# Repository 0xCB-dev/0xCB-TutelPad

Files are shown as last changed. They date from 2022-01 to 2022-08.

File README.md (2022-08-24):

# 0xcb-TutelPad
## An 8-key macropad with a 128x64 pixel OLED display

Licence | OSHWA
:-------------------------:|:-------------------------:
 | (https://certification.oshwa.org/nl000009.html)

### Available here:

[KeebSupply](https://keeb.supply/products/0xcb-tutelpad)

### QMK

[keyboards/0xcb/tutelpad/](https://github.com/qmk/qmk_firmware/tree/master/keyboards/0xcb/tutelpad)

#### Flashing

* `qmk clone`
* `cd qmk_firmware`
* `export LTO=Y`
* Press switch 1 while plugging in to go into dfu mode (or the reset button)
* `make 0xcb/tutelpad:via:flash`

### Assembly:

You can use the [humanpnp](https://files.0xcb.dev/0xCB-TutelPad/humanpnp.html) to easily place components.

### PCB:
KiCad 6 stable release - using these [libs](https://github.com/0xCB-dev/0xcb-libs)

Top | Bottom
:-------------------------:|:-------------------------:
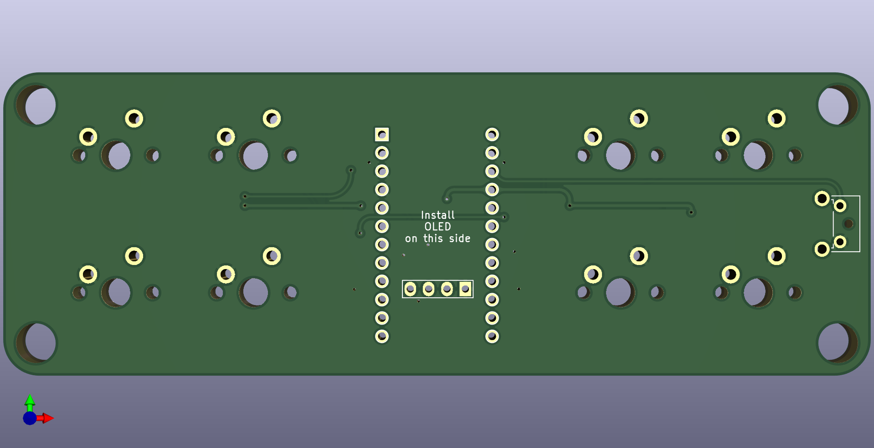
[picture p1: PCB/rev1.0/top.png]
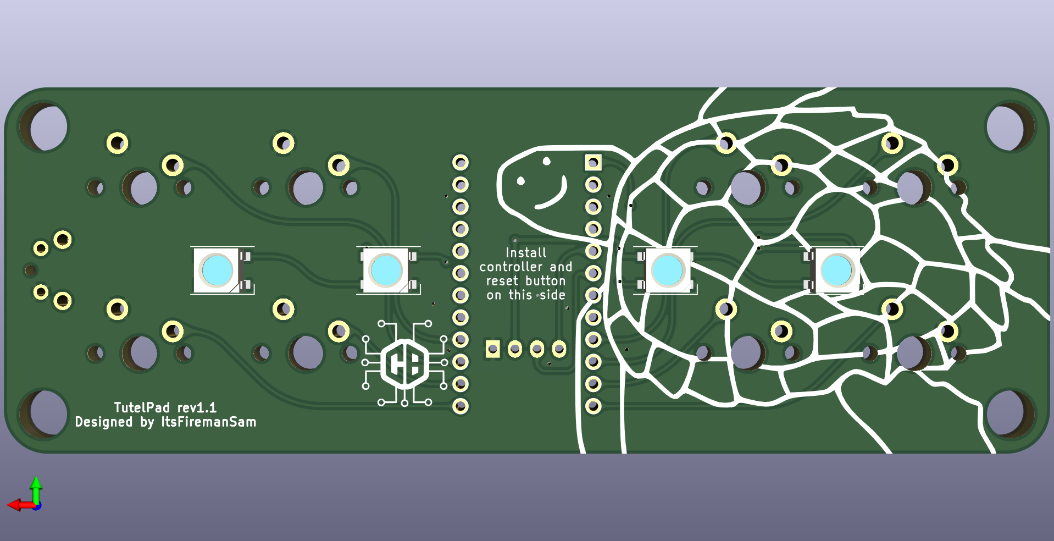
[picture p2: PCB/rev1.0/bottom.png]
  |  

### CAD files:

[DXF](https://github.com/0xCB-dev/0xCB-TutelPad/tree/main/CAD/DXF)

#### BOM:
 References                        | Value          | Quantity | Part Nb.            
-----------------------------------|----------------|----------|---------------------
 SW1                               | SPST RA        | 1        | C115343             
 RGB4,RGB3,RGB2,RGB1               | WS2812B        | 4        | C114586             
 OL1                               | SSD1306-128x64 | 1        | amazon

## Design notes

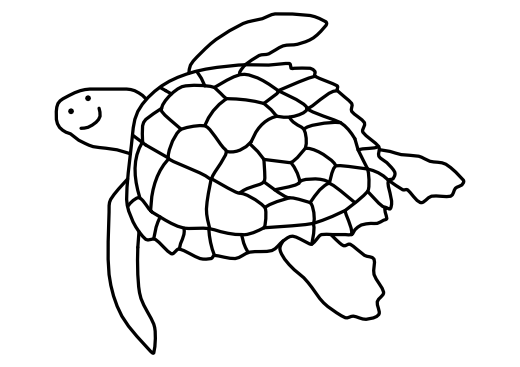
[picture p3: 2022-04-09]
PCB/rev1.0/artwork/tutel.png

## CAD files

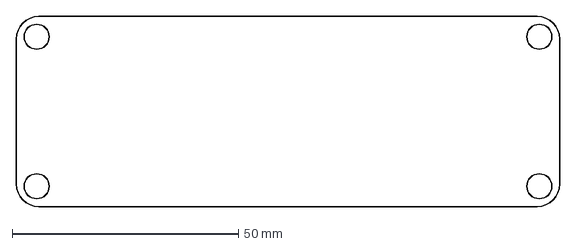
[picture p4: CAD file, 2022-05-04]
CAD/DXF/PCB.DXF
120.0 x 42.0 mm

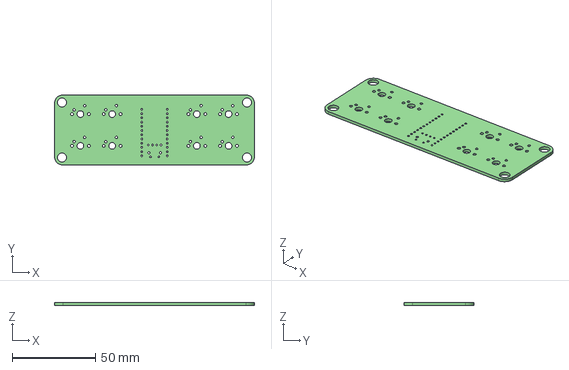
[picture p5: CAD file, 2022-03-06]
kicad/rev1.1/TurtlePad.step
120.0 x 42.0 x 1.60 mm

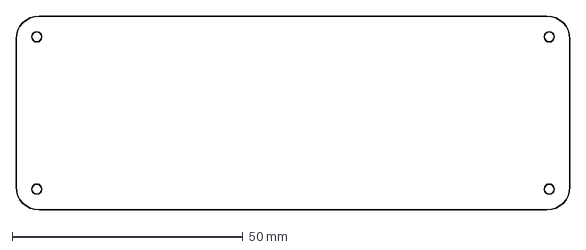
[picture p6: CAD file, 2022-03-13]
CAD/DXF/bottom plate.DXF
120.0 x 42.0 mm

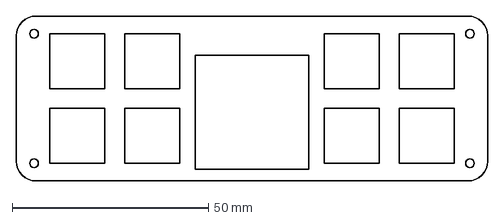
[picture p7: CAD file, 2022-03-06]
CAD/DXF/switch plate.DXF
120.0 x 42.0 mm

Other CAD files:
Solidworks/PCB.DXF

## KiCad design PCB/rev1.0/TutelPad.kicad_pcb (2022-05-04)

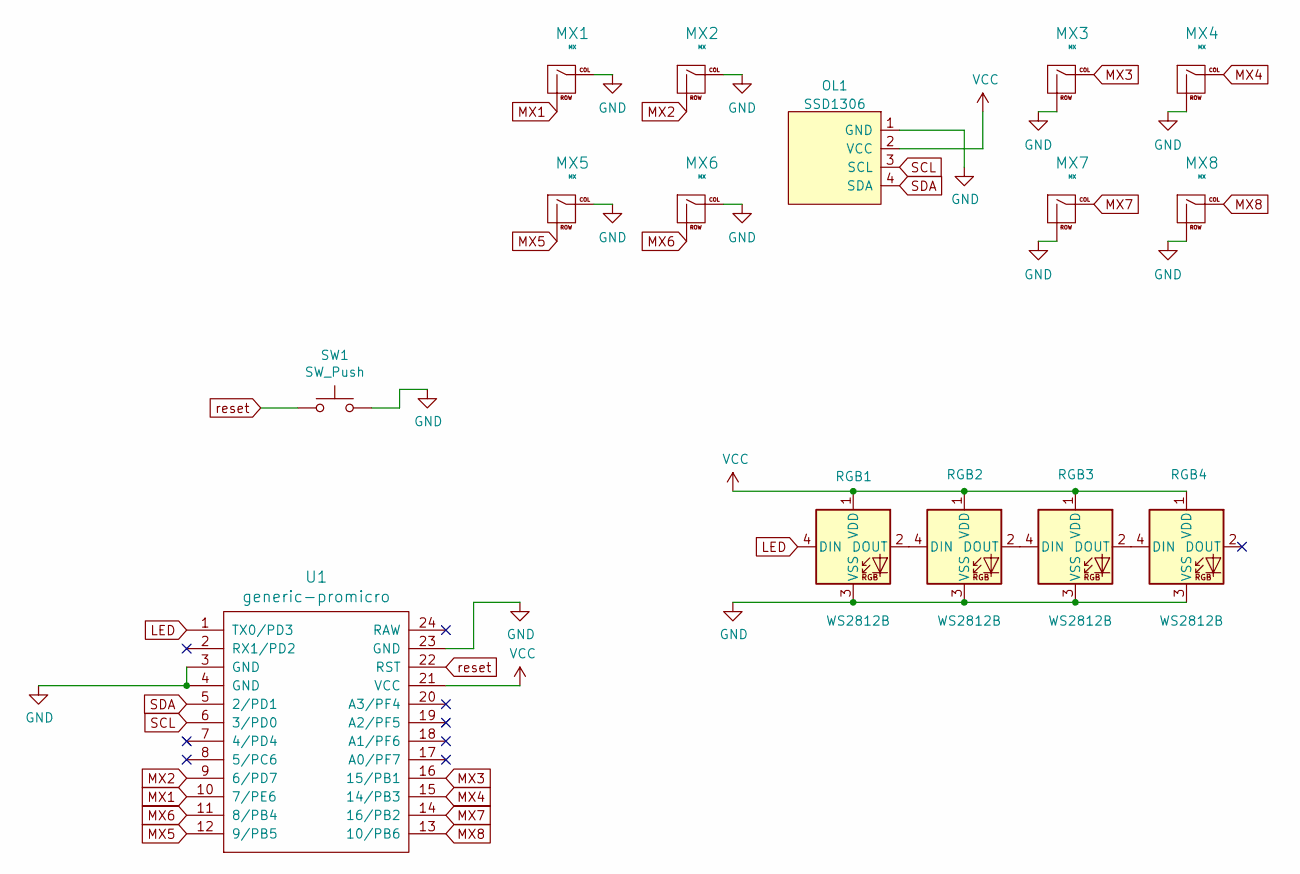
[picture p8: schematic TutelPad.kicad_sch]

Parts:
MX1, MX2, MX3, MX4, MX5, MX6, MX7, MX8: MX; SW_Cherry_MX_PCB_1.00u
OL1: SSD1306; 128x64OLED
RGB1, RGB2, RGB3, RGB4: WS2812B; LED_WS2812B_PLCC4_5.0x5.0mm_P3.2mm
SW1: SW_Push; SW_Tactile_SPST_Angled
U1: generic-promicro

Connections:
GND: MX1.1 (COL), MX2.1 (COL), MX3.2 (ROW), MX4.2 (ROW), MX5.1 (COL), MX6.1 (COL), MX7.2 (ROW), MX8.2 (ROW), OL1.1 (GND), RGB1.3 (VSS), RGB2.3 (VSS), RGB3.3 (VSS), RGB4.3 (VSS), SW1.2, U1.3 (GND), U1.4 (GND), U1.23 (GND)
LED: RGB1.4 (DIN), U1.1 (TX0/PD3)
MX1: MX1.2 (ROW), U1.10 (7/PE6)
MX2: MX2.2 (ROW), U1.9 (6/PD7)
MX3: MX3.1 (COL), U1.16 (15/PB1)
MX4: MX4.1 (COL), U1.15 (14/PB3)
MX5: MX5.2 (ROW), U1.12 (9/PB5)
MX6: MX6.2 (ROW), U1.11 (8/PB4)
MX7: MX7.1 (COL), U1.14 (16/PB2)
MX8: MX8.1 (COL), U1.13 (10/PB6)
unnamed: RGB1.2 (DOUT), RGB2.4 (DIN)
unnamed: RGB2.2 (DOUT), RGB3.4 (DIN)
unnamed: RGB3.2 (DOUT), RGB4.4 (DIN)
SCL: OL1.3 (SCL), U1.6 (3/PD0)
SDA: OL1.4 (SDA), U1.5 (2/PD1)
VCC: OL1.2 (VCC), RGB1.1 (VDD), RGB2.1 (VDD), RGB3.1 (VDD), RGB4.1 (VDD), U1.21 (VCC)
reset: SW1.1, U1.22 (RST)

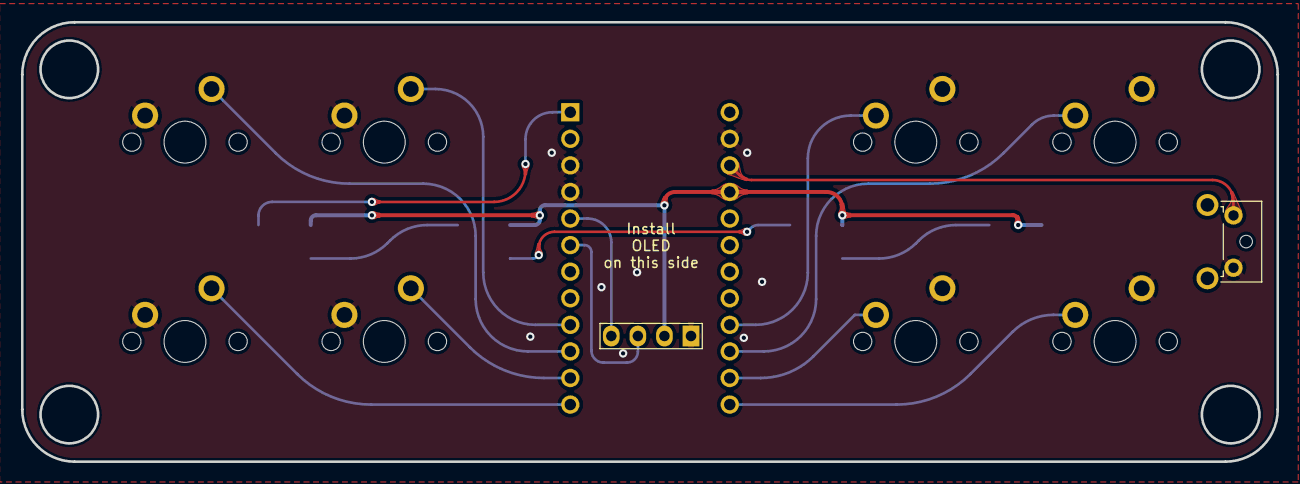
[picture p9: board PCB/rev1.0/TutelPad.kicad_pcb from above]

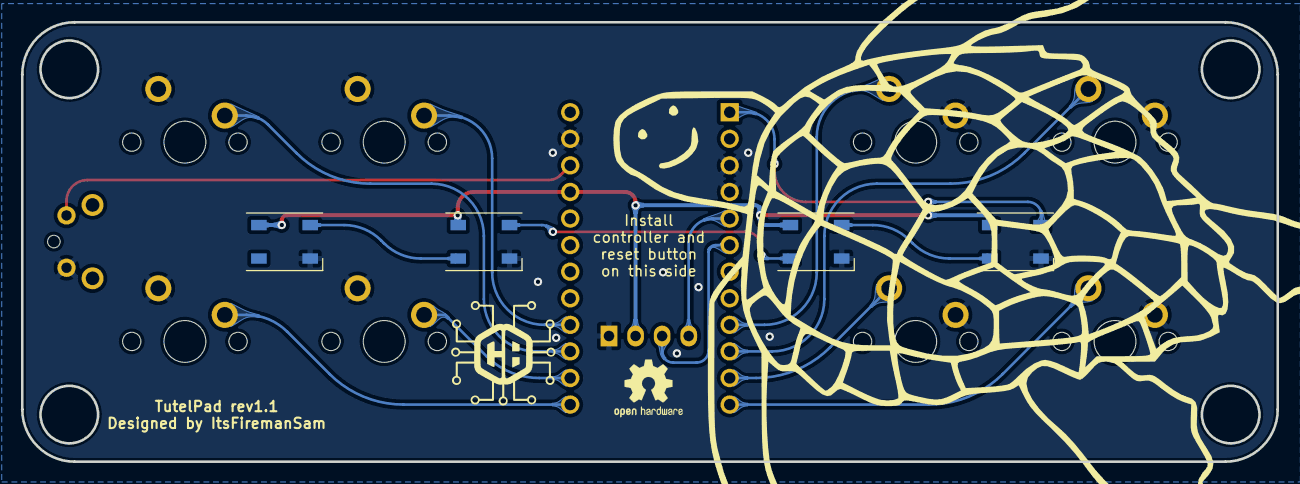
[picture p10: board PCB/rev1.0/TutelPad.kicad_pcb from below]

Board: 2 copper layers, 120.0 x 42.0 mm, 15 parts (4 on the bottom side), 17 nets.

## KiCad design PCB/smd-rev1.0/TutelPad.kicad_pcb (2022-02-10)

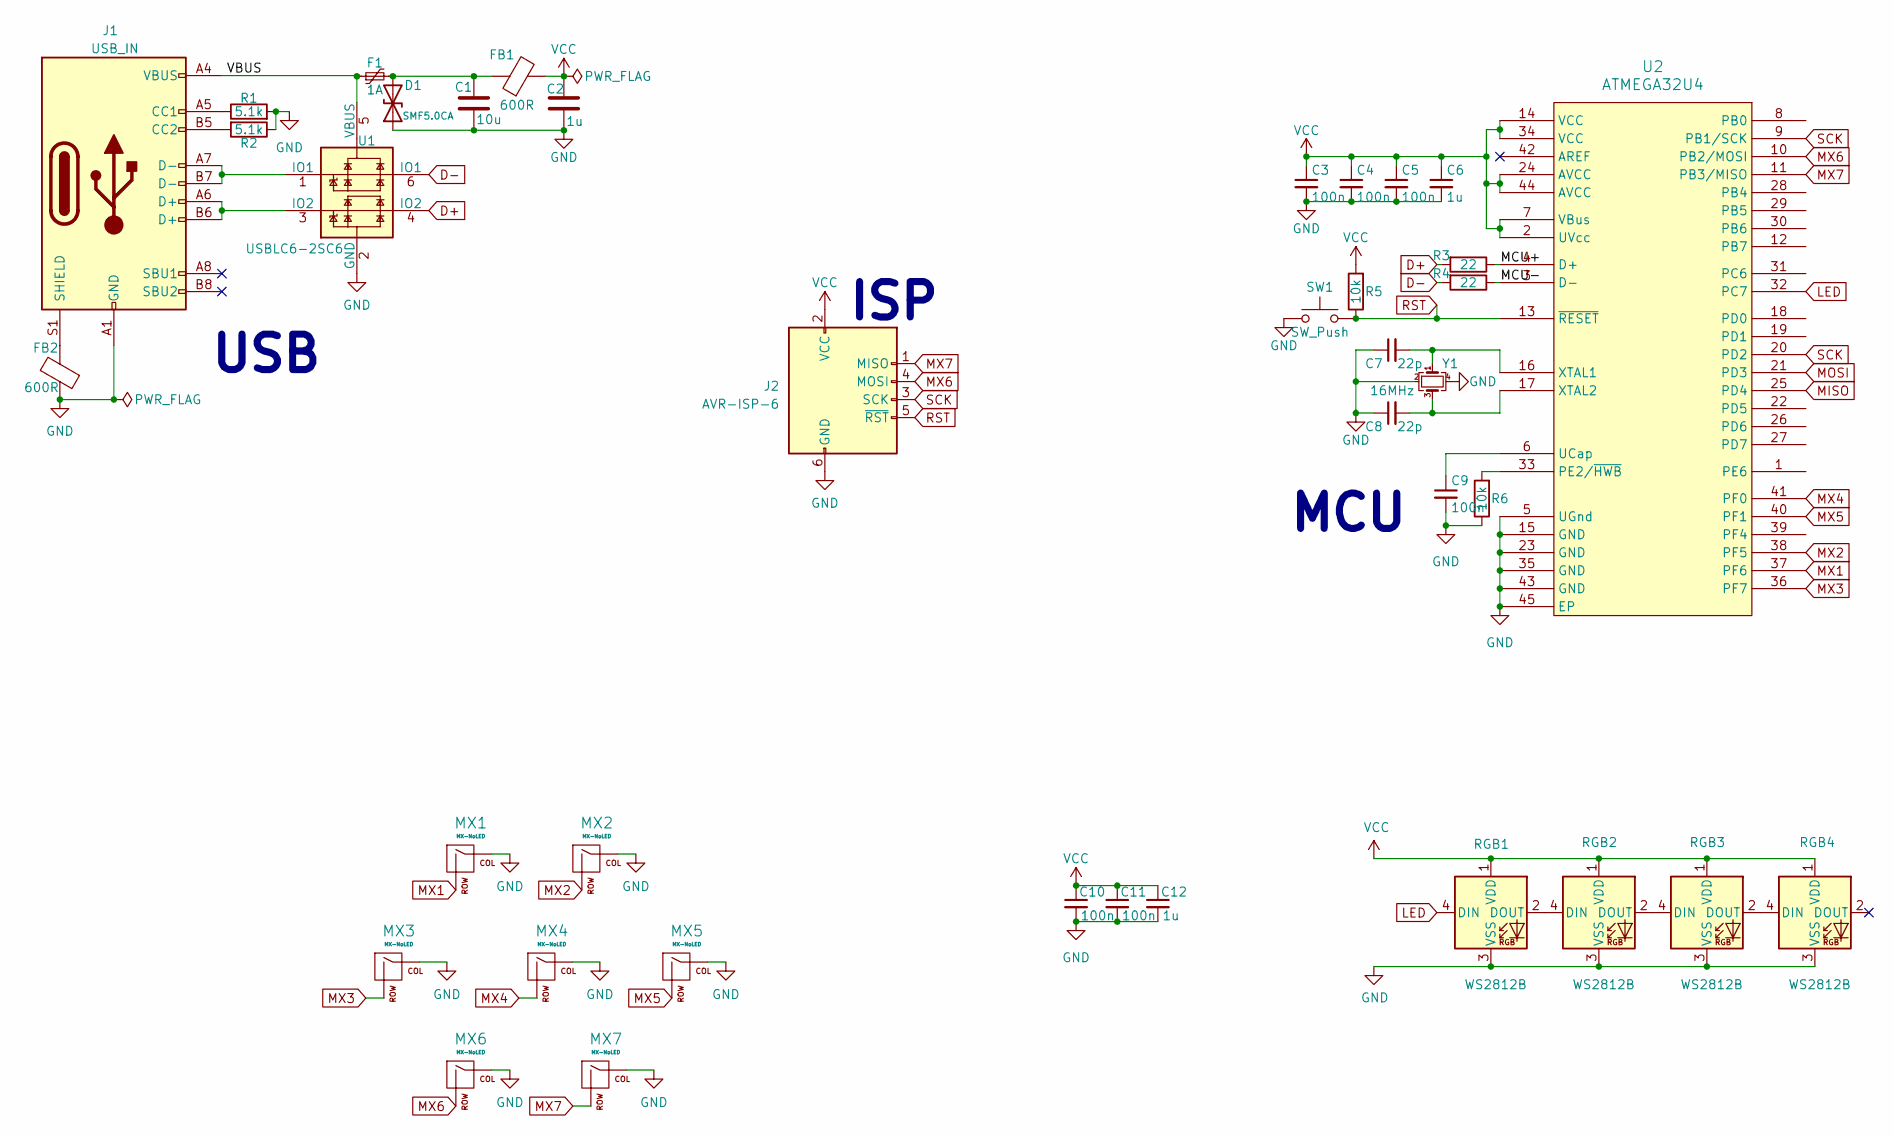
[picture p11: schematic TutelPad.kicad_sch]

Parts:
C1: 10u; C_0603_1608Metric
C2: 1u; C_0603_1608Metric
C3, C4, C5, C10, C11: 100n; C_0603_1608Metric; Part Nb. 478-5266-1-ND
C6: 1u; C_0603_1608Metric; Part Nb. 1276-1102-1-ND
C7, C8: 22p; C_0603_1608Metric; Part Nb. 478-1167-1-ND
C9: 100n; C_0603_1608Metric; Part Nb. 1276-1102-1-ND
C12: 1u; C_0603_1608Metric; Part Nb. 478-5266-1-ND
D1: SMF5.0CA; D_SOD-123F
F1: 1A; Fuse_0805_2012Metric; Part Nb. 507-1815-1-ND
FB1: 600R; Ferrite_Bead_0603
FB2: 600R; Ferrite_Bead_0603; Part Nb. 732-1593-1-ND
J1: USB_IN; molex2169900001; Part Nb. 900-2169900002CT-ND
J2: AVR-ISP-6; AVR_PROG_2.54_THT
MX1, MX2, MX3, MX4, MX5, MX6, MX7: MX-NoLED; SW_Cherry_MX_PCB_1.00u
R1, R2: 5.1k; R_0603_1608Metric; Part Nb. P5.1KDBCT-ND
R3, R4: 22; R_0603_1608Metric; Part Nb. A130081CT-ND
R5, R6: 10k; R_0603_1608Metric; Part Nb. RHM10KADCT-ND
RGB1, RGB2, RGB3, RGB4: WS2812B; LED_WS2812B_PLCC4_5.0x5.0mm_P3.2mm
SW1: SW_Push; SW_SPST_TL3342; Part Nb. EG2531CT-ND
U1: USBLC6-2SC6; SOT-23-6; Part Nb. 497-5235-1-ND
U2: ATMEGA32U4; QFN-44-1EP_7x7mm_P0.5mm_EP5.2x5.2mm_ThermalVias; Part Nb. ATMEGA32U4RC-MURCT-ND
Y1: 16MHz; Crystal_SMD_3225-4Pin_3.2x2.5mm; Part Nb. XC2060CT-ND

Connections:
/MCU+: R3.1, U2.4 (D+)
/MCU-: R4.1, U2.3 (D-)
/VBUS: F1.1, J1.A4 (VBUS), J1.A9 (VBUS), J1.B4 (VBUS), J1.B9 (VBUS), U1.5 (VBUS)
D+: R3.2, U1.4 (IO2)
D-: R4.2, U1.6 (IO1)
GND: C1.2, C2.2, C3.2, C4.2, C5.2, C6.2, C7.1, C8.1, C9.2, C10.2, C11.2, C12.2, D1.1 (A1), FB2.1, J1.A1 (GND), J1.A12 (GND), J1.B1 (GND), J1.B12 (GND), J2.6 (GND), MX1.1 (COL), MX2.1 (COL), MX3.1 (COL), MX4.1 (COL), MX5.1 (COL), MX6.1 (COL), MX7.1 (COL), R1.2, R2.1, R6.1, RGB1.3 (VSS), RGB2.3 (VSS), RGB3.3 (VSS), RGB4.3 (VSS), SW1.1, U1.2 (GND), U2.5 (UGnd), U2.15 (GND), U2.23 (GND), U2.35 (GND), U2.43 (GND), U2.45 (EP), Y1.2, Y1.4
LED: RGB1.4 (DIN), U2.32 (PC7)
MISO: U2.25 (PD4)
MOSI: U2.21 (PD3)
MX1: MX1.2 (ROW), U2.37 (PF6)
MX2: MX2.2 (ROW), U2.38 (PF5)
MX3: MX3.2 (ROW), U2.36 (PF7)
MX4: MX4.2 (ROW), U2.41 (PF0)
MX5: MX5.2 (ROW), U2.40 (PF1)
MX6: J2.4 (MOSI), MX6.2 (ROW), U2.10 (PB2/MOSI)
MX7: J2.1 (MISO), MX7.2 (ROW), U2.11 (PB3/MISO)
unnamed: C1.1, D1.2 (A2), F1.2, FB1.1
unnamed: C7.2, U2.16 (XTAL1), Y1.1
unnamed: C8.2, U2.17 (XTAL2), Y1.3
unnamed: C9.1, U2.6 (UCap)
unnamed: FB2.2, J1.S1 (SHIELD)
unnamed: J1.A5 (CC1), R1.1
unnamed: J1.A6 (D+), J1.B6 (D+), U1.3 (IO2)
unnamed: J1.A7 (D-), J1.B7 (D-), U1.1 (IO1)
unnamed: J1.B5 (CC2), R2.2
unnamed: R6.2, U2.33 (PE2/~HWB)
unnamed: RGB1.2 (DOUT), RGB2.4 (DIN)
unnamed: RGB2.2 (DOUT), RGB3.4 (DIN)
unnamed: RGB3.2 (DOUT), RGB4.4 (DIN)
RST: J2.5 (~RST), R5.1, SW1.2, U2.13 (~RESET)
SCK: J2.3 (SCK), U2.9 (PB1/SCK), U2.20 (PD2)
VCC: C2.1, C3.1, C4.1, C5.1, C6.1, C10.1, C11.1, C12.1, FB1.2, J2.2 (VCC), R5.2, RGB1.1 (VDD), RGB2.1 (VDD), RGB3.1 (VDD), RGB4.1 (VDD), U2.2 (UVcc), U2.7 (VBus), U2.14 (VCC), U2.24 (AVCC), U2.34 (VCC), U2.44 (AVCC)

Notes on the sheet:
USB
ISP
MCU

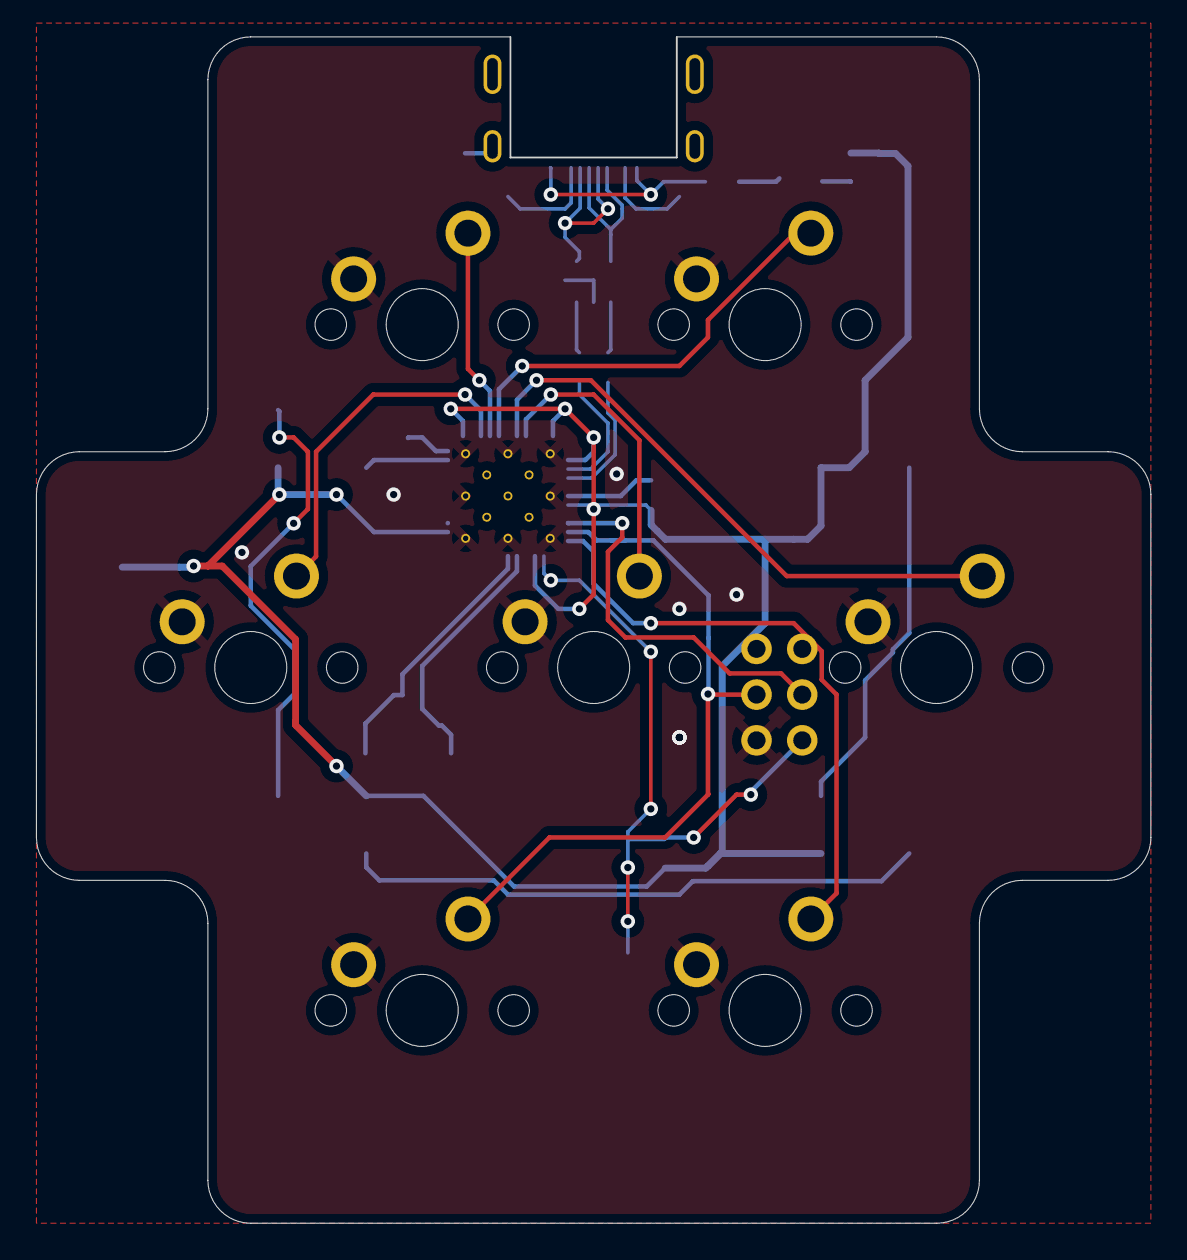
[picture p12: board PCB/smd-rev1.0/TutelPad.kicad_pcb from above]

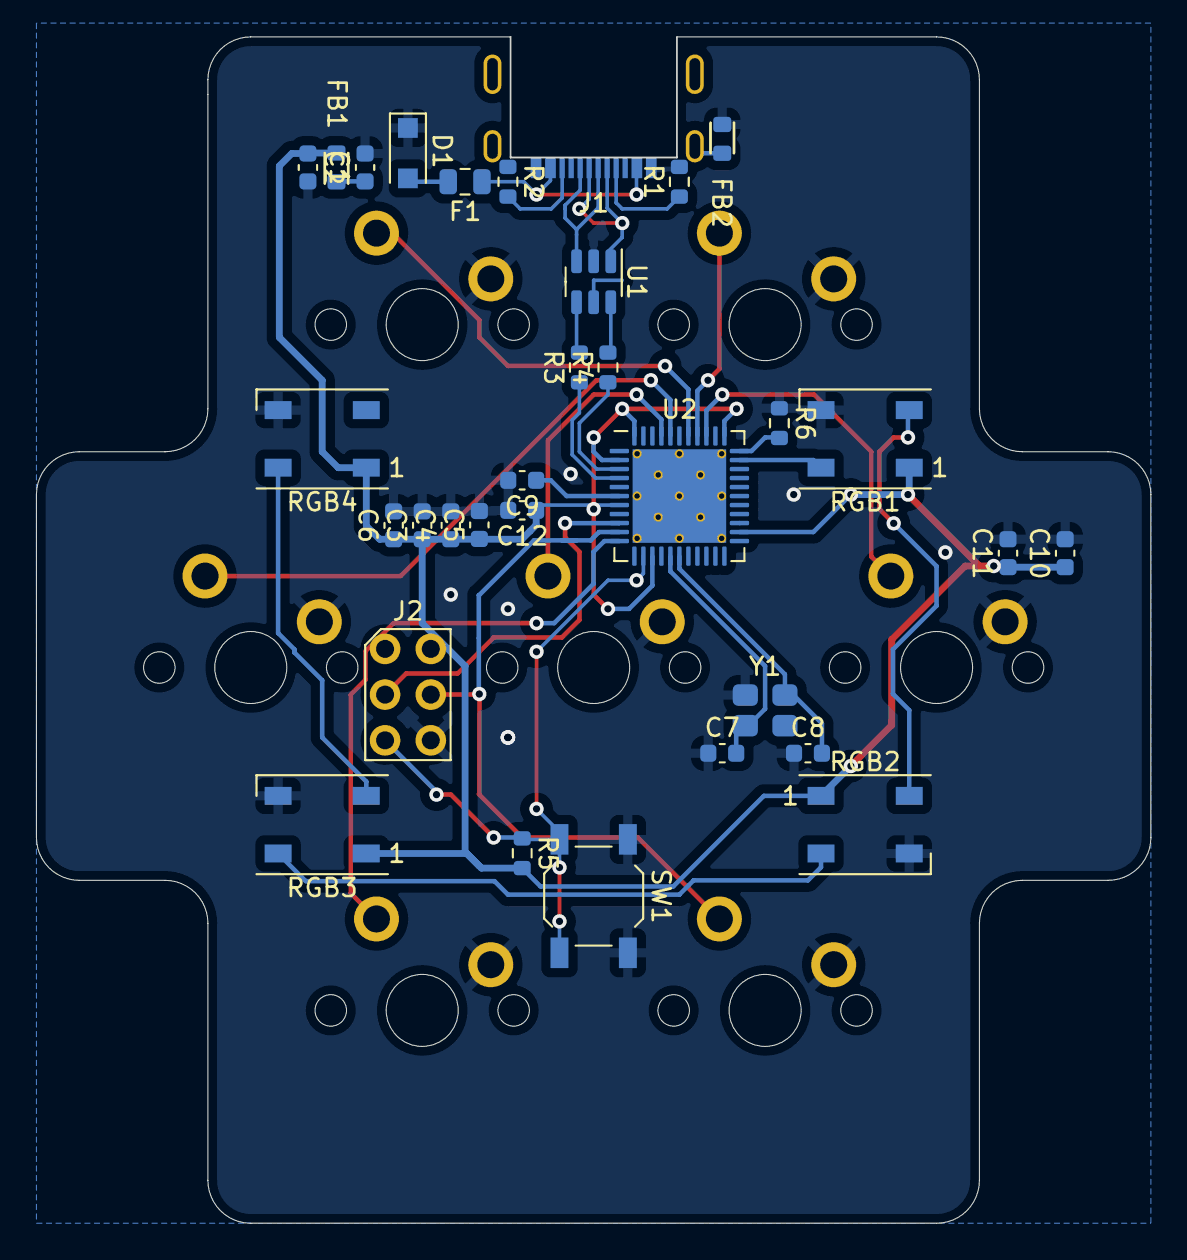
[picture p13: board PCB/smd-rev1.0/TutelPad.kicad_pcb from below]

Board: 2 copper layers, 61.9 x 65.9 mm, 39 parts (32 on the bottom side), 30 nets.

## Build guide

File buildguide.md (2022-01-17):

# TurtlePad buildguide WIP
1. (Optional) Solder on the WS2812B LEDs (this is the first step because it would be hard to solder them on nicely if you have other parts in the way).
2. Solder the diodes (currently just THT diodes). Make sure you match the black line on the diode with the thicker white line on the PCB.
3. Solder in the hotswap sockets. You can use Kailh or Gateron sockets, make sure the cutouts for the switches are clear, so you can actually insert a switch.
For a quick guide on how to solder these sockets: [soldering Kailh hotswap sockets](https://imgur.com/ThIzfro).
4. Solder the reset switch **on the top of the PCB**.
5. Solder the Pro Micro controller on the back of the PCB, with the smooth side towards the PCB. Be sure to cut the legs nice and short on the top of the PCB.
6. Solder in the OLED. Be sure you solder it on the top of the PCB (where the switches go).

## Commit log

2021-12-19 Initialize project
    [AdderPad.kicad_pcb, AdderPad.sch]
2021-12-19 Add footprint submodule
2021-12-19 Added libraries, fixed folder structure
    [AdderPad.kicad_pcb, AdderPad.sch]
2021-12-19 Finished PCB
    [AdderPad.sch]
2021-12-21 Added angled reset button
    [AdderPad.sch]
2021-12-21 Added RGB underglow LEDs
    Rerouted traces, new mill sizes
    [AdderPad.kicad_pcb, AdderPad.sch]
2021-12-21 Multiple updates
    - added 128x64 OLED support
    - added fourth underglow RGB
    - resize PCB
    [AdderPad.kicad_pcb, AdderPad.sch]
2021-12-21 Final name changes
    [TurtlePad.kicad_pcb]
2021-12-22 fixed some minor stuff, updated the outline, added solidworks folder for DXFs
    [PCB.DXF, PCB.SLDPRT, TurtlePad.kicad_pcb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]
2021-12-23 Added switch plate and backplate folders
    [TurtlePad.kicad_pcb, TurtlePad.kicad_sch, TurtlePad.sch]
2021-12-30 plates and prod files
    [0.96_128x64 OLED yellow & blue.stp, Baugruppe.SLDASM, Bottom Plate.SLDPRT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]
2022-01-22 Started work on rev1.1
    [TurtlePad-B_Cu.gbr, TurtlePad-B_Mask.gbr, TurtlePad-B_Paste.gbr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]
2022-01-22 Fix filling
    [TurtlePad.kicad_pcb]
2022-01-25 Added designer silkscreen
    [TurtlePad.kicad_pcb]
2022-02-09 rev1.1 again
    [TurtlePad.kicad_pcb, TurtlePad.kicad_sch, TurtlePad.sch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]
2022-02-09 cleaned up, rounded traces added teardrops
    [TurtlePad.kicad_pcb]
2022-02-09 Placed all surface mount parts for now
    Just need to figure out how in God's name to route all of it
    [TurtlePad.kicad_pcb]
2022-02-09 Revert "Placed all surface mount parts for now"
    This reverts commit df8ecd82c21d147e971f6b322fb3575a65e4f200.
    [TurtlePad.kicad_pcb]
2022-02-09 Revert "Revert "Placed all surface mount parts for now""
    This reverts commit 42bec52487df9ac41952cb28762131b75d3db880.
    [TurtlePad.kicad_pcb]
2022-02-10 Redid schematic because I am an idiot
    [TurtlePad.kicad_pcb, TurtlePad.kicad_sch]
2022-02-10 Placed and routed all components on PCB
    [TurtlePad.kicad_pcb, TurtlePad.kicad_sch]
2022-02-10 PCB edge and copper fill
    [TurtlePad.kicad_pcb]
2022-03-03 Fix LED without GND
    [TurtlePad.kicad_pcb]
2022-03-13 changed PCB, added switch and bottom plate, added gerbers
    [Turtle.step, TurtlePad-B_Mask.dxf, TurtlePad-Edge_Cuts.dxf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]
2022-04-09 TutelPad transformation
    Updated the silkscreen, renamed all files to TutelPad, renamed rev1.1 to rev1.0
    [0.96_128x64 OLED yellow & blue.stp.SLDPRT, Turtle.step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]
2022-04-09 silkscreen on switch and backplate
    [bottomplate.kicad_pcb, switchplate.kicad_pcb]
2022-04-15 cleaned repo and changed libs
    [0.96_128x64 OLED yellow & blue.stp, 0.96_128x64 OLED yellow & blue.stp.SLDPRT, Bottom Plate.SLDPRT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]
2022-04-15 fixing the readme
    [TutelPad-B_Cu.gbr, TutelPad-B_Mask.gbr, TutelPad-B_Paste.gbr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]
2022-05-04 fixed board outline
    [PCB.DXF, TutelPad.kicad_pcb]
2022-08-24 git update
    [Bottom Plate.SLDPRT, M2 Screw.SLDPRT, PCB.SLDPRT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]
